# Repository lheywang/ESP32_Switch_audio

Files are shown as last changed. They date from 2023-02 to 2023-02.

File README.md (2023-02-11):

# ESP32_Switch_audio
A small audio_switch, controlled via WiFi. He has two functionnality : 
- Selection from one 3.5mm jack, and output it to the fourth 3.5mm jack.
- Speaker switch : from one input, you can enable or disable up to 4 pairs of speaker, independently.

Recommendations :
- The switch use an 5V Micro-USB type B as power supply (on the ESP32 Devboard). The PCB take power from the VUSB / 5V pin.
  So, take care to use a USB power who can deliver at least 1A (1.5A is recommended).
 
- As i said, the system take power from the micro USB port on ESP32 Devboard. So take care to buy an ESP32 who HAVE this port. Not all boards have one.

- The system does not include any amps, you will need it !
- The board is designed for something like 60W of power. The relay can handle up to 250VAC / 8A, so you have some freedom with power.

How to use it ?
To deploy the system, it needs 2 pieces of software : Arduino IDE (1.8.9) and ESP32 Sketch Data Upload (not supported on Arduino 2.x versions).
1) Modify the code for you (insert your wifi SSID and password)
2) flash the data using the tool on the SPIFFS. Don't forget to press the button "boot" on the ESP32 board to enable flash.
3) flash the code. Don't forget to press the button "boot" on the ESP32 board to enable flash.
4) Using en serial monitor, check if the ESP32 can make WiFi connection, and note the local IP printed on the monitor. You will need this to acces to the web page, using your brothers
5) Put the switch in place, and enjoy !

Hardware notes :
- The system is designed to maintain a correct impedance for the amps.
Pairs 1 and 2, when both activated are wired in serial, as like as Pairs 3 and 4.
These two pairs of output are wired in parallel. 
These design to achieve 2 speaker in serial, and 2 in parallel.

In the worst case, you will get 1/2 of the speaker impedance, and in the other case you will get the double of the nominal impedance.
Take care to wire it correctly : 

- 1 pairs : anywhere
- 2 pairs : 1 + 2 / 3 + 3 (1 + 3 / 2 + 4 will work, at 1/2 of the impedance, you can choose | by default it's 2x impedance.)
- 3 pairs : 1 + 2 + 3
- 4 pairs : 1 + 2 + 3 + 4

I use 7 sealed relay, to prevent damage from external conditions (audio signal cannot clean the switches, so they need to be sealed)

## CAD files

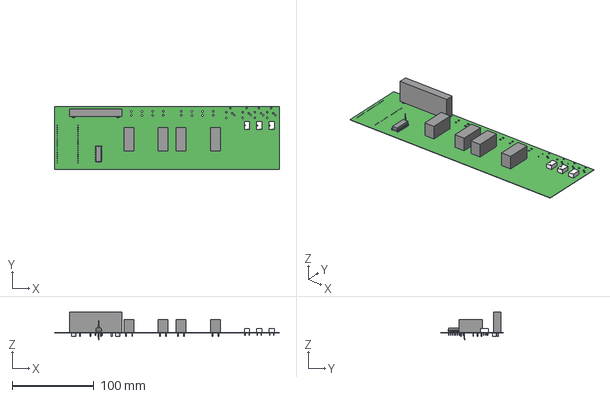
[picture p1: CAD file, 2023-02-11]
PCB2.step
275.1 x 77.0 x 34.1 mm

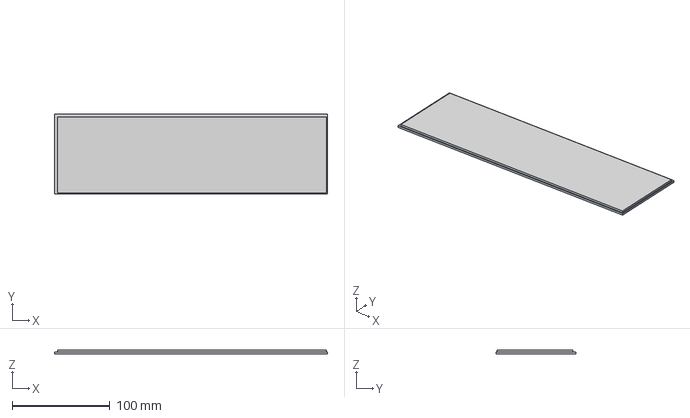
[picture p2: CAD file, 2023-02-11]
top.step
280.0 x 82.0 x 4.00 mm

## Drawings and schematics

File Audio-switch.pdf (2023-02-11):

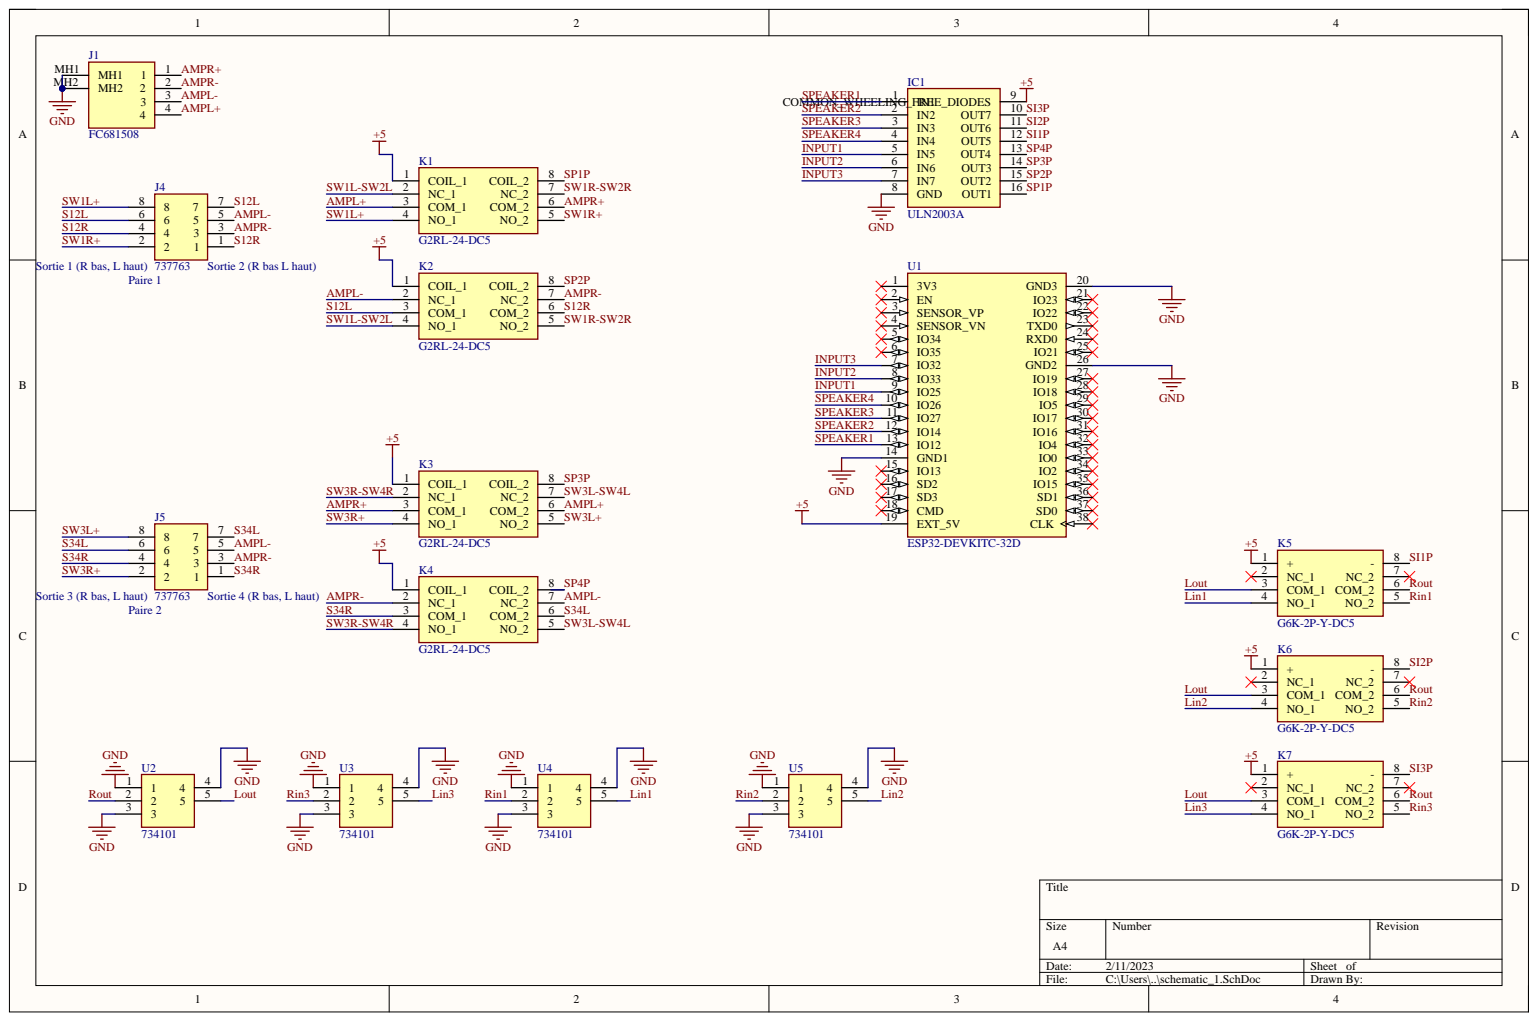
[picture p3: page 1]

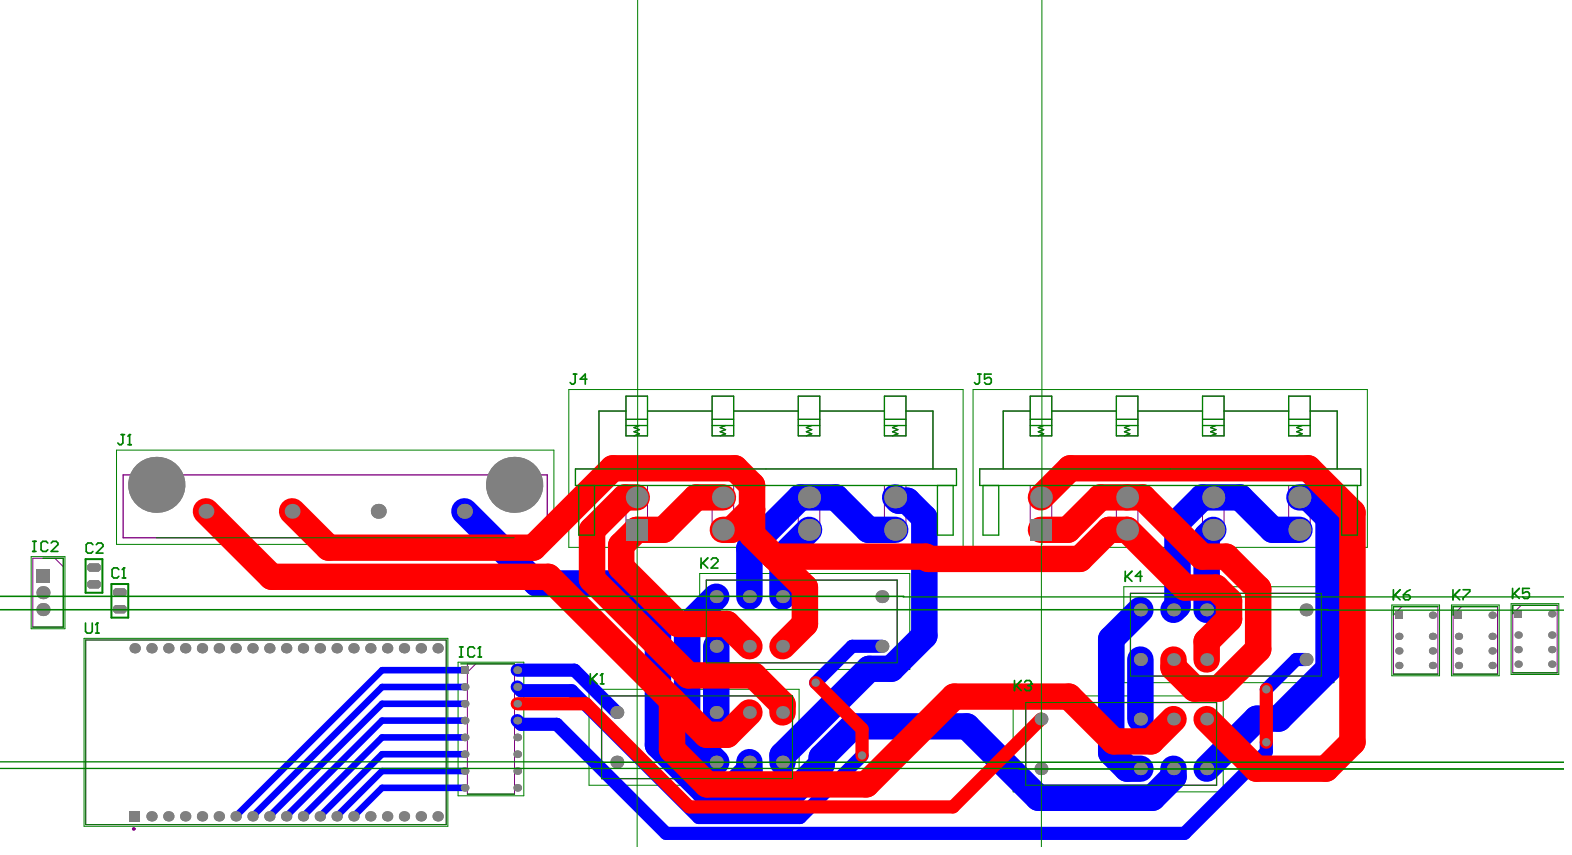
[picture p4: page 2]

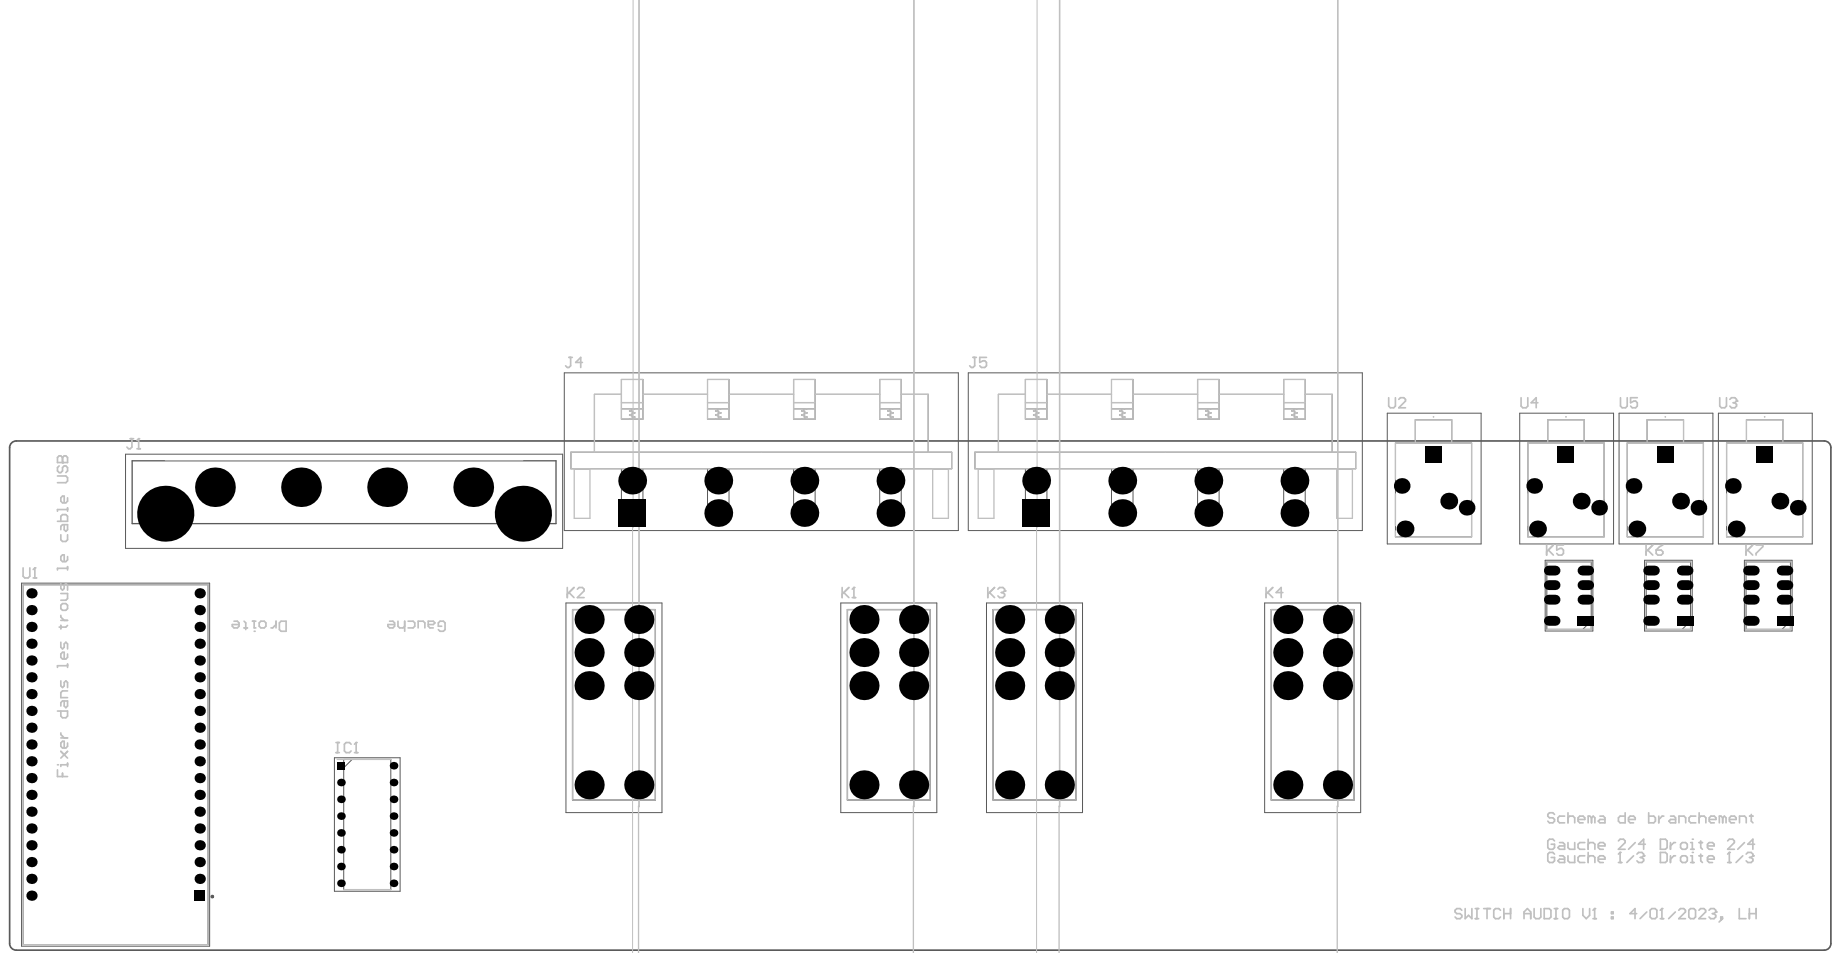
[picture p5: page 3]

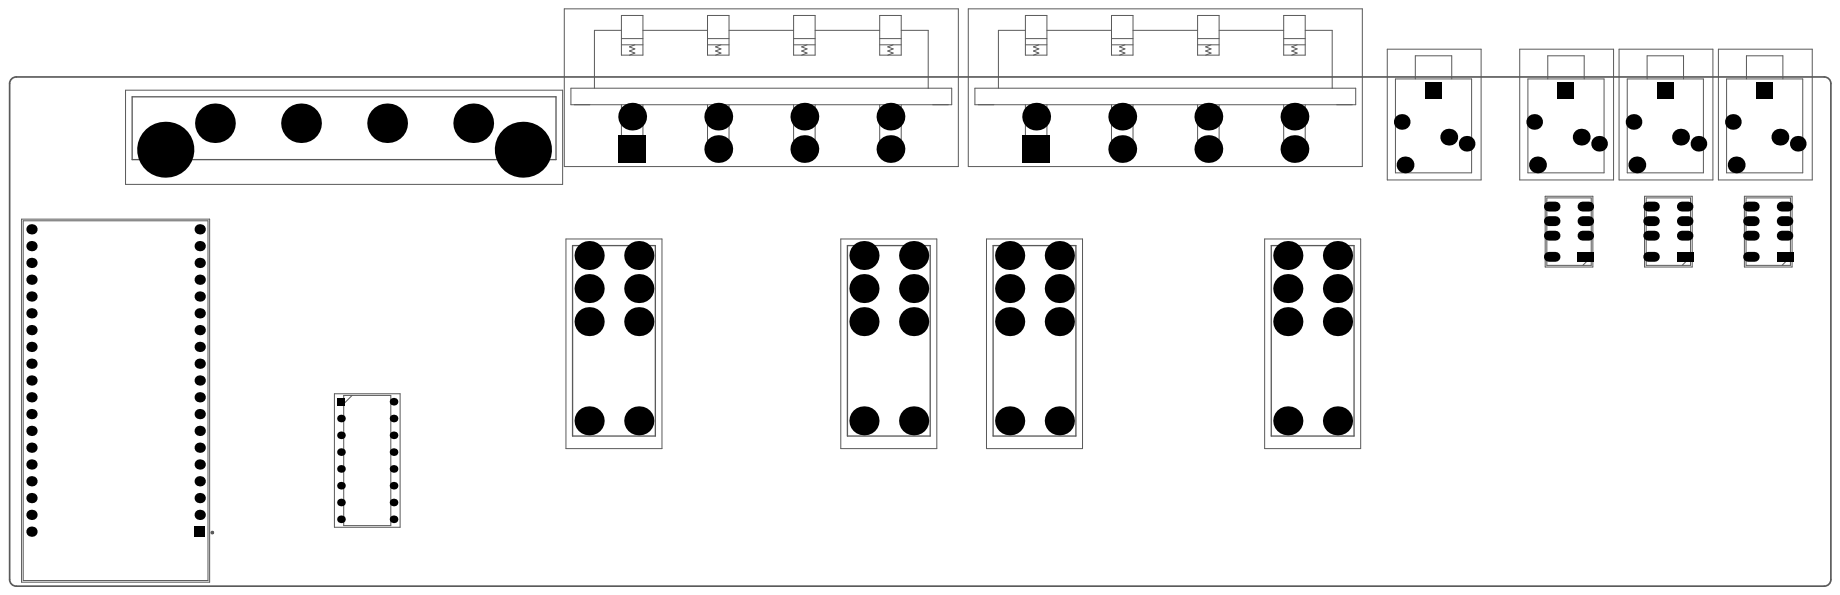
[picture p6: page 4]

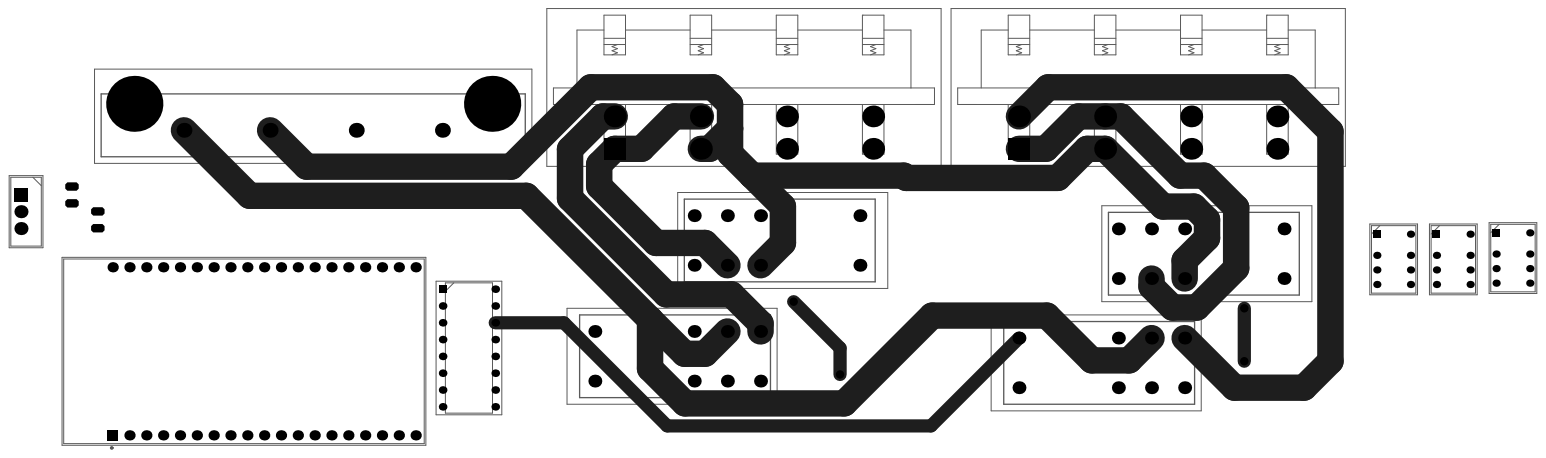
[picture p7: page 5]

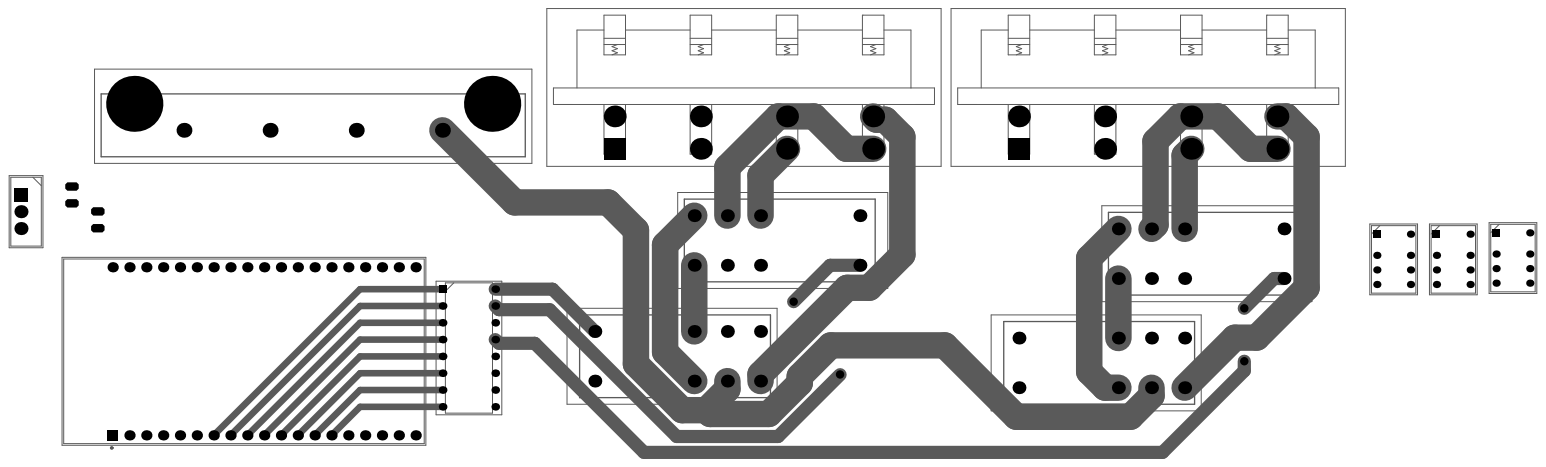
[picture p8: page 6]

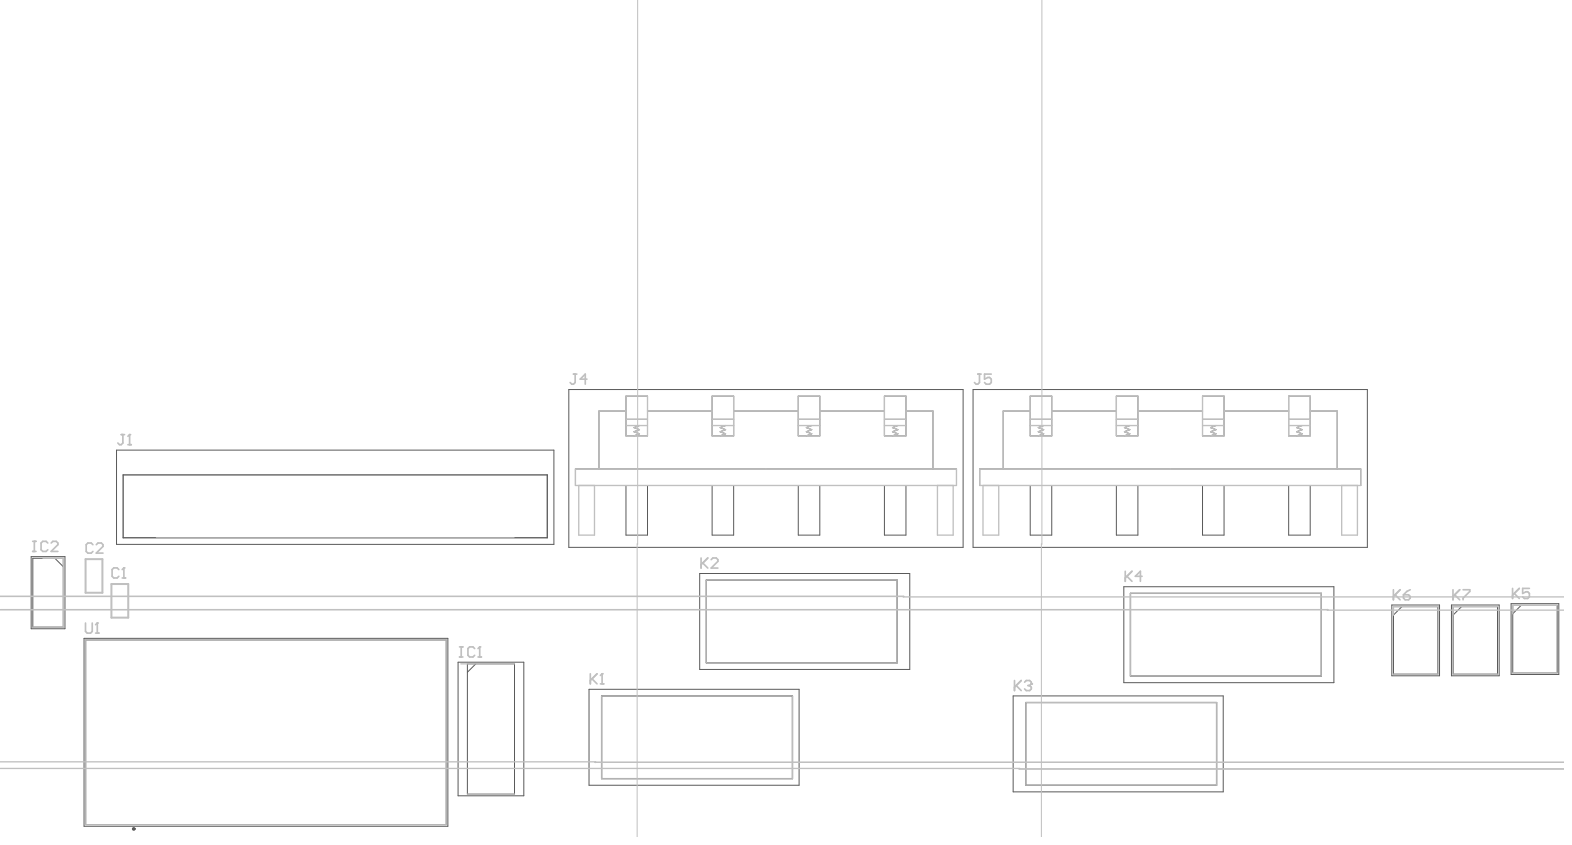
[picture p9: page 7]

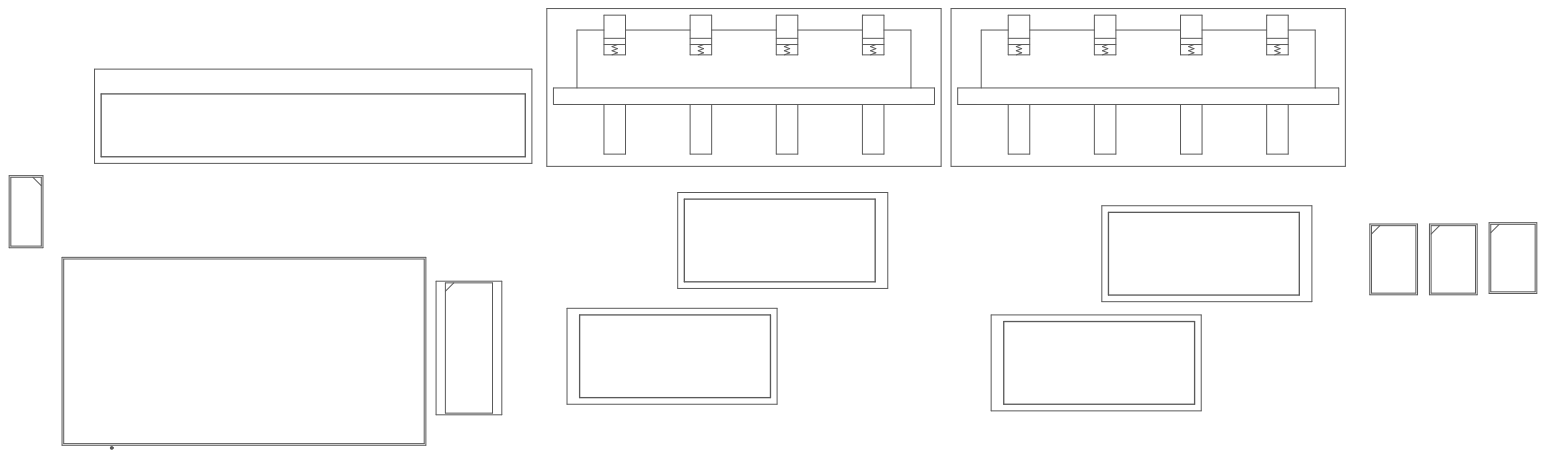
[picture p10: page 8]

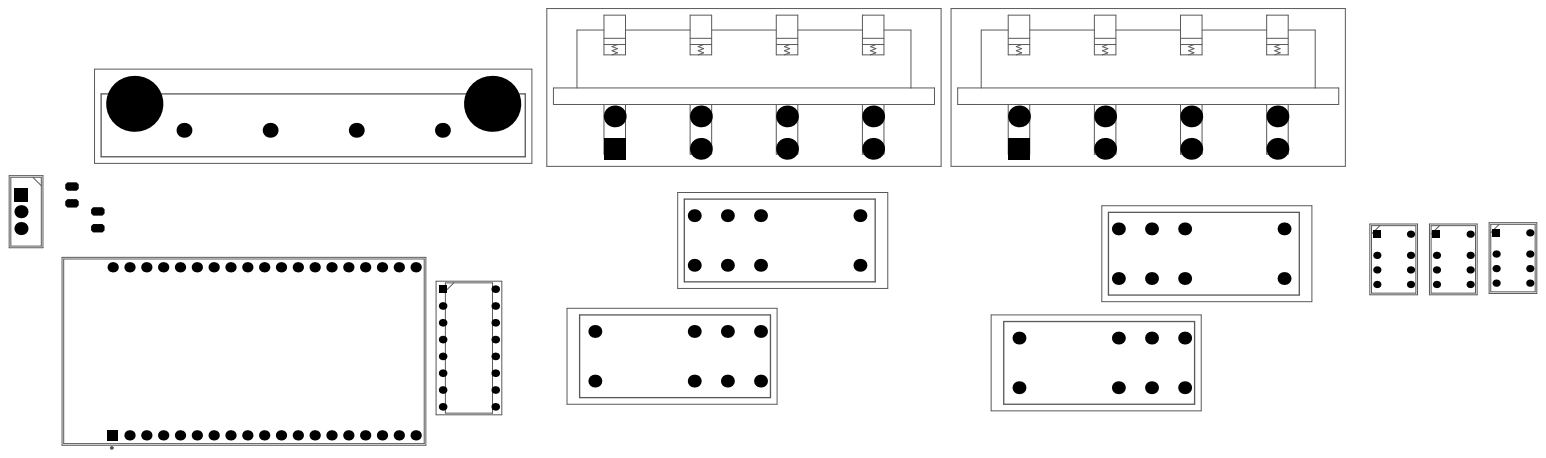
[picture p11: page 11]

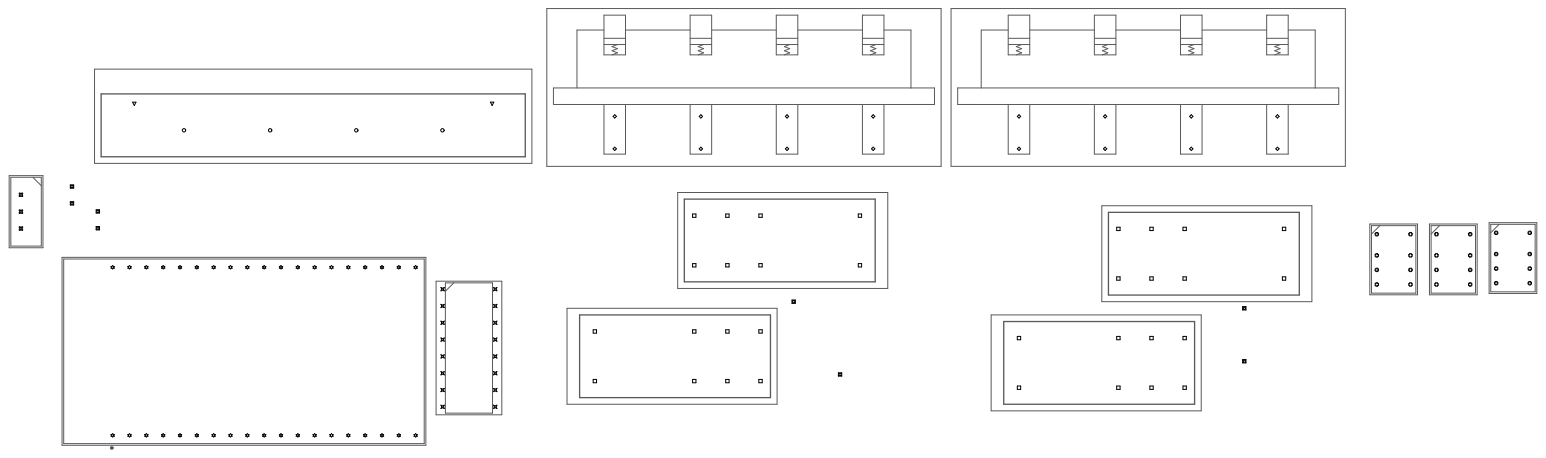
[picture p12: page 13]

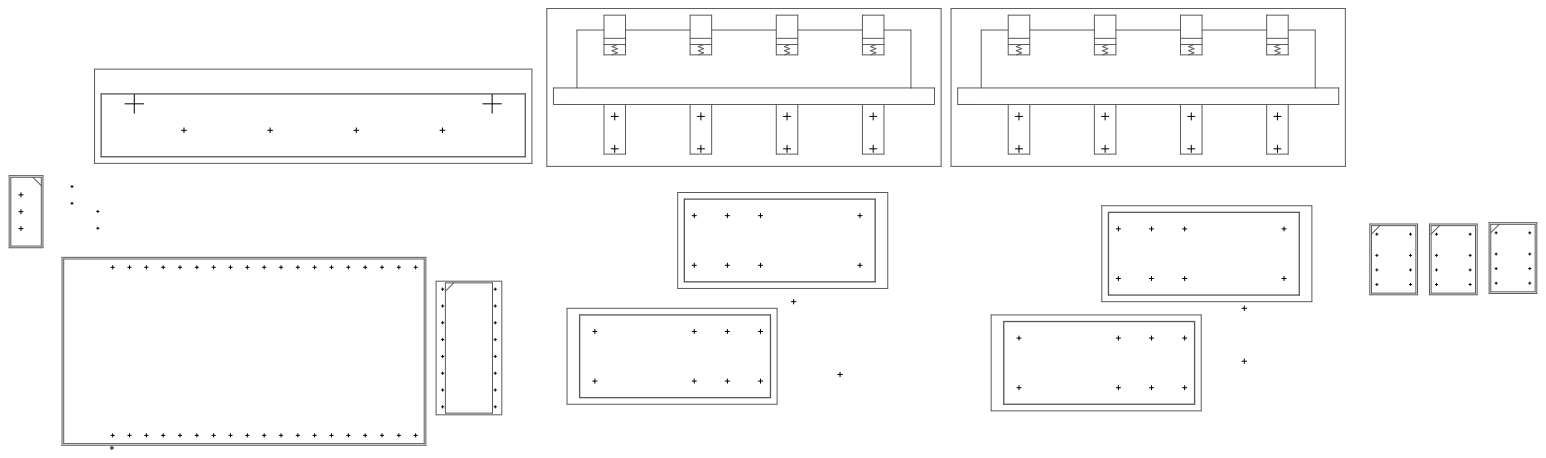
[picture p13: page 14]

# Electrical Rules Check Report

Class | Document | Message Successful Compile for
Saturday 11 Feb 2023 9:52:59 PM | Page 1 of 1

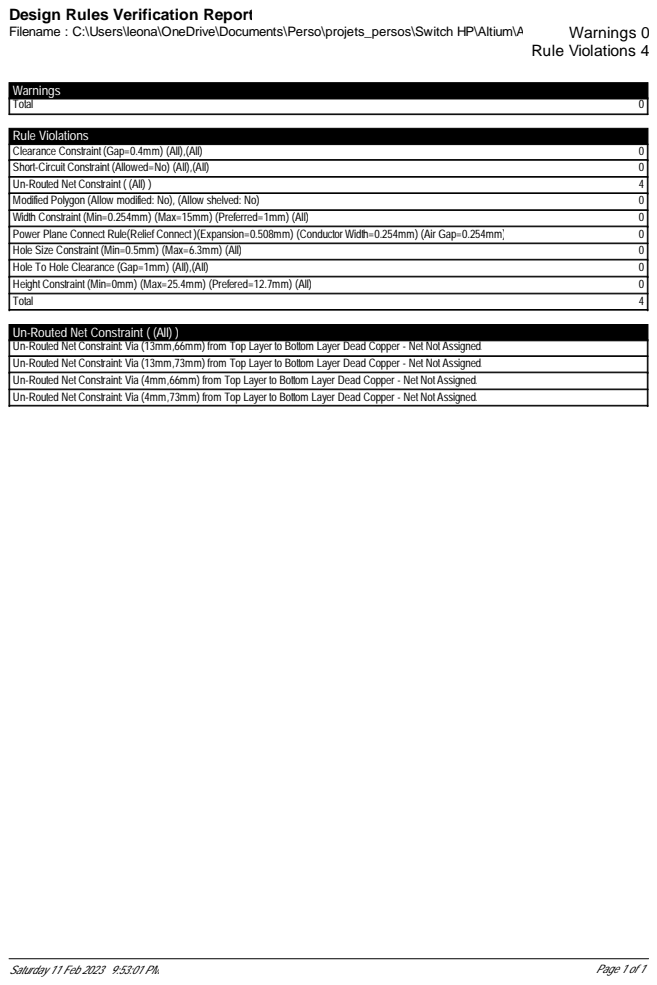
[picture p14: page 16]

Design Rules Verification Report

Un-Routed Net Constraint ( (All) )
Un-Routed Net Constraint: Via (13mm,66mm) from Top Layer to Bottom Layer Dead Copper - Net Not Assigned.
Un-Routed Net Constraint: Via (13mm,73mm) from Top Layer to Bottom Layer Dead Copper - Net Not Assigned.
Un-Routed Net Constraint: Via (4mm,66mm) from Top Layer to Bottom Layer Dead Copper - Net Not Assigned.
Un-Routed Net Constraint: Via (4mm,73mm) from Top Layer to Bottom Layer Dead Copper - Net Not Assigned.


Line # | Name | Description | Designator | Quantity | Manufacturer 1 | Manufacturer Part Number 1 | Manufacturer Lifecycle 1 | Supplier 1 | Supplier Part Number 1 | Supplier Unit Price 1 | Supplier Subtotal 1
4 pins speaker connector (input) | FC681508 | Connector | J1 | 1

8 pins speaker connector | 737763 | Connector | J4, J5 | 2

ESP32 | ESP32-DEVKITC-32D | Eval Board For Esp-Wroom-32 | U1 | 1

ESP32 protectio n for inductive loads | ULN2003A | Integrated Circuit | IC1 | 1

Relay (Speaker level) | G2RL-24-DC5 | Relay or Contactor | K1, K2, K3, K4 | 4

Relay (line level) | G6K-2P-Y-DC5 | Relay or Contactor | K5, K6, K7 | 3

Jack connector , TRU compone nts | 734101 | Undefined or Miscellaneous | U2, U3, U4, U5 | 4

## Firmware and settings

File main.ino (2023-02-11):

 #define FILESYSTEM SPIFFS
// You only need to format the filesystem once
#define FORMAT_FILESYSTEM false
#define MDNS_DEVICE_NAME "audio-switch"
#define SERVICE_NAME "audio-switch"
#define SERVICE_PROTOCOL "udp"
#define SERVICE_PORT 5600

// Base lib
#include <arduino.h>

// Wifi
#include <WiFi.h>

// Web server libs (DNS, async server, json ...)
#include <WebServer.h>
#include <ArduinoJson.h>
#include <ESPmDNS.h>
#include <AsyncTCP.h>
#include <ESPAsyncWebServer.h>

// Storage libs
#include <Preferences.h>
#include <SPIFFS.h>
#include <FS.h>

// RTC and timing libs
 #include <time.h>
 
// ----------- SETTINGS ---------------------------------------------------------------------------------------------------------------------------------------
const char * ssid = "your_wif_SSID";
const char * password = "your_password";
const char * host = "audio-switch"; // here the DNS name, you can edit it when you want.

const long  gmtOffset_sec = 3600; // Used to setup GMT Time, in seconds. By default it's setup to GMT+1. Only used for night off / on cycle
const int   daylightOffset_sec = 3600;

// ---------- PINOUT SETTINGS -----------------------------------------------------------------------------------------------------------------------------------------
#define SPEAKER1 12
#define SPEAKER2 14
#define SPEAKER3 27
#define SPEAKER4 26

#define INPUT1 25
#define INPUT2 33
#define INPUT3 32
#define INPUT4 18 // stay unused but can be implemented (this option need some hardware modifications)

// No limitation to pins usage, only the ESP32 limitation (ex : internal pull-up resistor)

// ---------- VARIABLES -----------------------------------------------------------------------------------------------------------------------------------------
typedef struct state {
    bool state_array[38];
    bool off_hour[24];
    
    String IN1_name;
    String IN2_name;
    String IN3_name;
    String IN4_name;

    String OUT1_name;
    String OUT2_name;
    String OUT3_name;
    String OUT4_name;

    bool HasBeenEdited;
    bool Mode;
    bool mtime;
    bool mtime2;

    bool NeedGoOn;
    bool NeedGoOff;
};

state board_state; // initializing the structure, globally. Will be store in EEPROM. 

const char * input_parameter1 = "id";
const char * input_parameter2 = "state";
const char * input_parameter3 = "name";
const char * input_parameter4 = "s";

String event_buffer;
char event_send[1024]; 
String HTTP_RES;
int HTTP_RES_ID;

hw_timer_t * timer = NULL;

const char* ntpServer = "pool.ntp.org";
struct tm timeinfo;



// --------- Alliases -----------------------------------------------------------------------------------------------------------------------------------------
Preferences pref;
#define DBG_OUTPUT_PORT Serial

AsyncWebServer server(80);
AsyncEventSource events("/sse");
File fsUploadFile;

//--------- FUNCTIONS -----------------------------------------------------------------------------------------------------------------------------------------

void pins_init() {

    pinMode(SPEAKER1, OUTPUT);
    pinMode(SPEAKER2, OUTPUT);
    pinMode(SPEAKER3, OUTPUT);
    pinMode(SPEAKER4, OUTPUT);

    pinMode(INPUT1, OUTPUT);
    pinMode(INPUT2, OUTPUT);
    pinMode(INPUT3, OUTPUT);
    pinMode(INPUT4, OUTPUT);

    digitalWrite(SPEAKER1, LOW);
    digitalWrite(SPEAKER2, LOW);
    digitalWrite(SPEAKER3, LOW);
    digitalWrite(SPEAKER4, LOW);

    digitalWrite(INPUT1, LOW);
    digitalWrite(INPUT2, LOW);
    digitalWrite(INPUT3, LOW);
    digitalWrite(INPUT4, LOW);
}
String SetSpeakerOn(int ID) // activate a speaker and set in the board_state structure the actual state
{
    uint8_t ID_t;
    char buffer_name[10];
    if (ID == SPEAKER1) {ID_t = 1;}
    else if (ID == SPEAKER2) {ID_t = 2;}
    else if (ID == SPEAKER3) {ID_t = 3;}
    else if (ID == SPEAKER4) {ID_t = 4;}
    sprintf(buffer_name, "%s%d", "SPEAKER", ID_t);
    pref.putBool(buffer_name, true);
    board_state.state_array[ID] = true;
    if (board_state.Mode == true) {board_state.HasBeenEdited = true;}
    digitalWrite(ID, HIGH);
    return String(buffer_name);
}
String SetSpeakerOff(int ID) // desactivate a speaker and set in the board_state structure the actual state
{
    uint8_t ID_t;
    char buffer_name[10];
    if (ID == SPEAKER1) {ID_t = 1;}
    else if (ID == SPEAKER2) {ID_t = 2;}
    else if (ID == SPEAKER3) {ID_t = 3;}
    else if (ID == SPEAKER4) {ID_t = 4;}
    sprintf(buffer_name, "%s%d", "SPEAKER", ID_t);
    pref.putBool(buffer_name, false);
    board_state.state_array[ID] = false;
    if (board_state.Mode == true) {board_state.HasBeenEdited = true;}
    digitalWrite(ID, LOW);
    return String(buffer_name);
}
String SetInput(int ID) // Enable an input, and set all other to 0
{
    board_state.state_array[INPUT1] = false;
    board_state.state_array[INPUT2] = false;
    board_state.state_array[INPUT3] = false;
    board_state.state_array[INPUT4] = false;

    digitalWrite(INPUT1, LOW);
    digitalWrite(INPUT2, LOW);
    digitalWrite(INPUT3, LOW);
    digitalWrite(INPUT4, LOW);

    pref.putBool("INPUT1", false);
    pref.putBool("INPUT2", false);
    pref.putBool("INPUT3", false);
    pref.putBool("INPUT4", false);
    // the function begins with a reset of all inputs / state array / eeprom

    uint8_t ID_t;
    char buffer_name[10];
    if (ID == INPUT1) {ID_t = 1;}
    else if (ID == INPUT2) {ID_t = 2;}
    else if (ID == INPUT3) {ID_t = 3;}
    else if (ID == INPUT4) {ID_t = 4;}
    
    sprintf(buffer_name, "%s%d", "INPUT", ID_t);
    pref.putBool(buffer_name, true);
    board_state.state_array[ID] = true;
    
    if (board_state.Mode == true) {board_state.HasBeenEdited = true;}
    
    digitalWrite(ID, HIGH);
    return String(buffer_name);
    // activate the outputs and save in the rights places the data
}
void memory_init() {
    pref.begin("board_state", false);
}
void memory_read() // need to be done at start
{
    board_state.state_array[SPEAKER1] = pref.getBool("SPEAKER1", false);
    board_state.state_array[SPEAKER2] = pref.getBool("SPEAKER2", false);
    board_state.state_array[SPEAKER3] = pref.getBool("SPEAKER3", false);
    board_state.state_array[SPEAKER4] = pref.getBool("SPEAKER4", false);

    board_state.state_array[INPUT1] = pref.getBool("INPUT1", false);
    board_state.state_array[INPUT2] = pref.getBool("INPUT2", false);
    board_state.state_array[INPUT3] = pref.getBool("INPUT3", false);
    board_state.state_array[INPUT4] = pref.getBool("INPUT4", false);

    digitalWrite(SPEAKER1, board_state.state_array[SPEAKER1]);
    digitalWrite(SPEAKER2, board_state.state_array[SPEAKER2]);
    digitalWrite(SPEAKER3, board_state.state_array[SPEAKER3]);
    digitalWrite(SPEAKER4, board_state.state_array[SPEAKER4]);

    digitalWrite(INPUT1, board_state.state_array[INPUT1]);
    digitalWrite(INPUT2, board_state.state_array[INPUT2]);
    digitalWrite(INPUT3, board_state.state_array[INPUT3]);
    digitalWrite(INPUT4, board_state.state_array[INPUT4]);

    // writing ton IO port, to match the state array and output state.

    board_state.OUT1_name = pref.getString("OUT1_NAME");
    board_state.OUT2_name = pref.getString("OUT2_NAME");
    board_state.OUT3_name = pref.getString("OUT3_NAME");
    board_state.OUT4_name = pref.getString("OUT4_NAME");

    board_state.IN1_name = pref.getString("IN1_NAME");
    board_state.IN2_name = pref.getString("IN2_NAME");
    board_state.IN3_name = pref.getString("IN3_NAME");
    board_state.IN4_name = pref.getString("IN4_NAME");
  
    for (int HOUR = 0; HOUR < 24; HOUR++)
    {
      char buf[8];
      sprintf(buf, "HOUR%d", HOUR);
      board_state.off_hour[HOUR] = pref.getBool(buf, false);
    }
}

String GenerateJsonPackage()
{
  StaticJsonDocument<1024> doc;
            
  JsonObject speakers = doc.createNestedObject("speakers");
  speakers["1"] = board_state.state_array[SPEAKER1];
  speakers["2"] = board_state.state_array[SPEAKER2];
  speakers["3"] = board_state.state_array[SPEAKER3];
  speakers["4"] = board_state.state_array[SPEAKER4];

  JsonObject sources = doc.createNestedObject("sources");
  sources["1"] = board_state.state_array[INPUT1];
  sources["2"] = board_state.state_array[INPUT2];
  sources["3"] = board_state.state_array[INPUT3];
  sources["4"] = board_state.state_array[INPUT4];

  JsonObject speakerNames = doc.createNestedObject("speakerNames");
  speakerNames["1"] = board_state.OUT1_name;
  speakerNames["2"] = board_state.OUT2_name;
  speakerNames["3"] = board_state.OUT3_name;
  speakerNames["4"] = board_state.OUT4_name;

  JsonObject inputsNames = doc.createNestedObject("inputsNames");
  inputsNames["1"] = board_state.IN1_name;
  inputsNames["2"] = board_state.IN2_name;
  inputsNames["3"] = board_state.IN3_name;
  inputsNames["4"] = board_state.IN4_name;

  JsonObject schedules = doc.createNestedObject("schedules");
  char buf[8];
  for (int k = 0; k < 24; k++)
  {
    sprintf(buf, "%d", k);
    schedules[buf] = board_state.off_hour[k];
  }
 
  String event_buffer;
  serializeJson(doc, event_buffer);

  return event_buffer;
}

void IRAM_ATTR isOnorOff() // timer interrupt, place the system in eco mode or active mode according to schedules
{
  getLocalTime(&timeinfo);
  ets_printf("%d\n", timeinfo.tm_hour);
  
  if (board_state.off_hour[timeinfo.tm_hour] == true) // If the actual hour is on night mode
  {
    if (board_state.off_hour[timeinfo.tm_hour - 1] == false) // If the last hour was on active mode, we set the modification bit to false. 
    {
       if (board_state.mtime == false) // is executed only the first time, when enterring in the off mode
       {
          board_state.Mode = true;
          board_state.HasBeenEdited = false;
          board_state.mtime = true; // prevent from resetting the modification bit detector every 5mn in the first HOUR
          board_state.mtime2 = false;

          board_state.NeedGoOff = true;
          ets_printf("Mode OFF activé \n");
       }
    }
  }
  else
  {
    if (board_state.HasBeenEdited == false)
    {
      if (board_state.mtime2 == false)
      {
        board_state.mtime = false;
        board_state.mtime2 = true;
        board_state.Mode = false;
        board_state.HasBeenEdited = false;

        board_state.NeedGoOn = true;   
        ets_printf("Mode OFF desactivé + paramètres resets \n"); 
      }
    }
    else 
      {
        if (board_state.mtime2 == false)
        {
          board_state.mtime = false;
          board_state.mtime2 = true;
          board_state.Mode = false;
          board_state.HasBeenEdited = false;
         
          ets_printf("Mode off desactivé + paramètres laissés tels quels \n");
        }
     }
  }
}

void SetName(int ID, String NAME)
{
  if (ID == SPEAKER1) {
    board_state.OUT1_name = NAME;
    pref.putString("OUT1_NAME", board_state.OUT1_name);
  }
  else if (ID == SPEAKER2) {
    board_state.OUT2_name = NAME;
    pref.putString("OUT2_NAME", board_state.OUT2_name);
  }
  else if (ID == SPEAKER3) {
    board_state.OUT3_name = NAME;
    pref.putString("OUT3_NAME", board_state.OUT3_name);
  }
  else if (ID == SPEAKER4) {
    board_state.OUT4_name = NAME;
    pref.putString("OUT4_NAME", board_state.OUT4_name);
  }
  else if (ID == INPUT1) {
    board_state.IN1_name = NAME;
    pref.putString("IN1_NAME", board_state.IN1_name);
  }
  else if (ID == INPUT2) {
    board_state.IN2_name = NAME;
    pref.putString("IN2_NAME", board_state.IN2_name);
  }
  else if (ID == INPUT3) {
    board_state.IN3_name = NAME;
    pref.putString("IN3_NAME", board_state.IN3_name);
  }
  else if (ID == INPUT4) {
    board_state.IN4_name = NAME;
    pref.putString("IN4_NAME", board_state.IN4_name);
  }
  if (board_state.Mode == 1) {board_state.HasBeenEdited = true;}
}

void InitNames()
{
  board_state.OUT1_name = "Sortie 1";
  board_state.OUT2_name = "Sortie 2";
  board_state.OUT3_name = "Sortie 3";
  board_state.OUT4_name = "Sortie 4";
  
  board_state.IN1_name = "Entrée 1";
  board_state.IN2_name = "Entrée 2";
  board_state.IN3_name = "Entrée 3";
  board_state.IN4_name = "Entrée 4";

  pref.putString("OUT1_NAME", board_state.OUT1_name);
  pref.putString("OUT2_NAME", board_state.OUT2_name);
  pref.putString("OUT3_NAME", board_state.OUT3_name);
  pref.putString("OUT4_NAME", board_state.OUT4_name);

  pref.putString("IN1_NAME", board_state.IN1_name);
  pref.putString("IN2_NAME", board_state.IN2_name);
  pref.putString("IN3_NAME", board_state.IN3_name);
  pref.putString("IN4_NAME", board_state.IN4_name);
}

void EnterOffMode()
{        
  pref.putBool("SPEAKER1_OFF", board_state.state_array[SPEAKER1]);
  pref.putBool("SPEAKER2_OFF", board_state.state_array[SPEAKER2]);
  pref.putBool("SPEAKER3_OFF", board_state.state_array[SPEAKER3]);
  pref.putBool("SPEAKER4_OFF", board_state.state_array[SPEAKER4]);
  pref.putBool("INPUT1_OFF", board_state.state_array[INPUT1]);
  pref.putBool("INPUT2_OFF", board_state.state_array[INPUT2]);
  pref.putBool("INPUT3_OFF", board_state.state_array[INPUT3]);
  pref.putBool("INPUT4_OFF", board_state.state_array[INPUT4]); // we save the actual state under a specific key

  board_state.state_array[SPEAKER1] = false;
  digitalWrite(SPEAKER1, LOW);
  board_state.state_array[SPEAKER2] = false;
  digitalWrite(SPEAKER2, LOW);
  board_state.state_array[SPEAKER3] = false; 
  digitalWrite(SPEAKER3, LOW);
  board_state.state_array[SPEAKER4] = false;
  digitalWrite(SPEAKER4, LOW);
  board_state.state_array[INPUT1] = false;
  digitalWrite(INPUT1, LOW);
  board_state.state_array[INPUT2] = false;
  digitalWrite(INPUT2, LOW);
  board_state.state_array[INPUT3] = false;
  digitalWrite(INPUT3, LOW);
  board_state.state_array[INPUT4] = false;
  digitalWrite(INPUT4, LOW); // setting to 0 all the I/O and actualizing the board_state array     
}
void LeaveOffMode()
{
  board_state.state_array[SPEAKER1] = pref.getBool("SPEAKER1_OFF", false);
  board_state.state_array[SPEAKER2] = pref.getBool("SPEAKER2_OFF", false);
  board_state.state_array[SPEAKER3] = pref.getBool("SPEAKER3_OFF", false);
  board_state.state_array[SPEAKER4] = pref.getBool("SPEAKER4_OFF", false);
  board_state.state_array[INPUT1] = pref.getBool("INPUT1_OFF", false);
  board_state.state_array[INPUT2] = pref.getBool("INPUT2_OFF", false);
  board_state.state_array[INPUT3] = pref.getBool("INPUT3_OFF", false);
  board_state.state_array[INPUT4] = pref.getBool("INPUT4_OFF", false);

  digitalWrite(SPEAKER1, board_state.state_array[SPEAKER1]);
  digitalWrite(SPEAKER2, board_state.state_array[SPEAKER2]);
  digitalWrite(SPEAKER3, board_state.state_array[SPEAKER3]);
  digitalWrite(SPEAKER4, board_state.state_array[SPEAKER4]);
  digitalWrite(INPUT1, board_state.state_array[INPUT1]);
  digitalWrite(INPUT2, board_state.state_array[INPUT2]);
  digitalWrite(INPUT3, board_state.state_array[INPUT3]);
  digitalWrite(INPUT4, board_state.state_array[INPUT4]);
}
void MemRes()
{
  for (uint8_t HOUR = 0; HOUR < 24; HOUR++)
    {
      char buf[8];
      sprintf(buf, "HOUR%d", HOUR);
      pref.putBool(buf, false);
      board_state.off_hour[HOUR] = false;

      pref.putBool("SPEAKER1_OFF", (bool)false);
      pref.putBool("SPEAKER2_OFF", (bool)false);
      pref.putBool("SPEAKER3_OFF", (bool)false);
      pref.putBool("SPEAKER4_OFF", (bool)false);
      pref.putBool("INPUT1_OFF", (bool)false);
      pref.putBool("INPUT2_OFF", (bool)false);
      pref.putBool("INPUT3_OFF", (bool)false);
      pref.putBool("INPUT4_OFF", (bool)false);

      pref.putBool("SPEAKER1", false);
      pref.putBool("SPEAKER2", false);
      pref.putBool("SPEAKER3", false);
      pref.putBool("SPEAKER4", false);

      pref.putBool("INPUT1", false);
      pref.putBool("INPUT2", false);
      pref.putBool("INPUT3", false);
      pref.putBool("INPUT4", false);

      InitNames();
    }
}

// ------------ MAIN CODE ---------------------------------------------------------------------------------------------------------------------------------------------
void setup() {
    // put your setup code here, to run once:
    /*
    pref.putBool("SPEAKER1_OFF", (bool)false);
    pref.putBool("SPEAKER2_OFF", (bool)false);
    pref.putBool("SPEAKER3_OFF", (bool)false);
    pref.putBool("SPEAKER4_OFF", (bool)false);
    pref.putBool("INPUT1_OFF", (bool)false);
    pref.putBool("INPUT2_OFF", (bool)false);
    pref.putBool("INPUT3_OFF", (bool)false);
    pref.putBool("INPUT4_OFF", (bool)false);

    for (uint8_t HOUR = 0; HOUR < 24; HOUR++)
    {
      char buf[8];
      sprintf(buf, "HOUR%d", HOUR);
      pref.putBool(buf, false);
    }
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
void loop() 
{
   if (board_state.NeedGoOff == true)
   {
      EnterOffMode();
      board_state.NeedGoOff = false;
      
      event_buffer = GenerateJsonPackage();
      event_buffer.toCharArray(event_send, event_buffer.length()+1);    
      events.send(event_send, "speaker", millis());
   }
   if (board_state.NeedGoOn == true)
   {
      LeaveOffMode();
      board_state.NeedGoOn = false;
      
      event_buffer = GenerateJsonPackage();
      event_buffer.toCharArray(event_send, event_buffer.length()+1);
      events.send(event_send, "speaker", millis());
   }  
}

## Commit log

2023-02-11 Add files via upload
    Added files :
    arduino code
    Data (html)
    gerber for the PCB
    3D files for the case
    [top.step]
2023-02-11 Add files via upload
    Added somes files :
    - Schematic (PDF)
    - PCB2.step : 3d file of the PCB, if you want to integrate the circuit in another case
    2 CAO files : schematic en PCB (made on altium 23)
    -- You will need libs to open it properly
    [PCB2.PcbDoc, PCB2.step, schematic_1.SchDoc]
